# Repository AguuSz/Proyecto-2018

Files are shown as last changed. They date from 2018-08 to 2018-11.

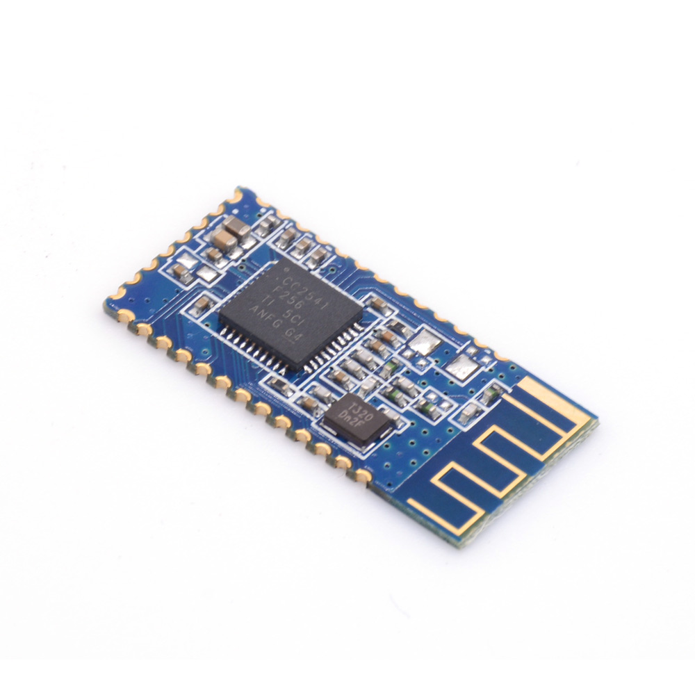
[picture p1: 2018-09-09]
Imagenes/hm_10_03.jpg

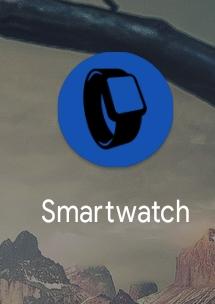
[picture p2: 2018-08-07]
Imagenes/2.jpeg

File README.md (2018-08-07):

# Proyecto 2018

En este repositorio se iran incluyendo los avances realizados en Arduino, ademas de ir adjuntando la bitacora actualizada para el proyecto 2018 "SmartWatch" del CET N°9. Realizado por Agustin Sepulveda, Marcos Marzeniuk y Emanuel Azurra.

Logo del colegio

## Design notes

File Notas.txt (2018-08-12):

// NOTAS //

La pantalla utilizada en el tutorial es de 28 * 64 OLED la cual estaba usando I2C y SSD1306 driver chip. Como estamos usando una diferente, lo mas seguro es que tengamos que usar unas librerias graficas diferentes y modificar el codigo fuente de Arduino

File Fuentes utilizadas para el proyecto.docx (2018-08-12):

Fuentes utilizadas para el proyecto

http://www.instructables.com/id/Make-your-own-smart-watch/

https://catinean.com/2015/03/07/creating-a-watch-face-with-android-wear-api/

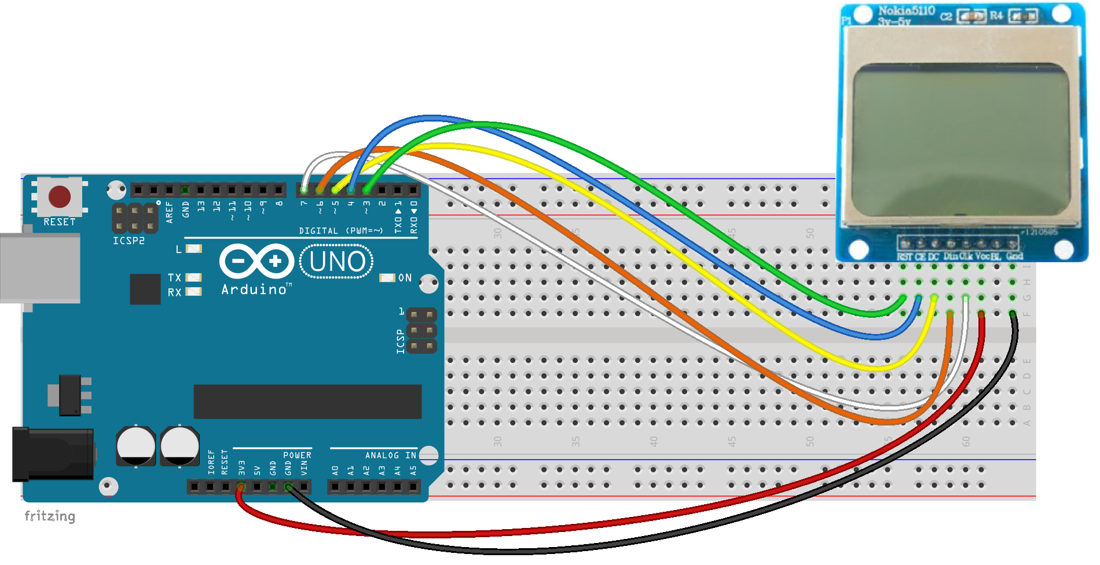
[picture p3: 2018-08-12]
Imagenes/Esquema de conexion.png

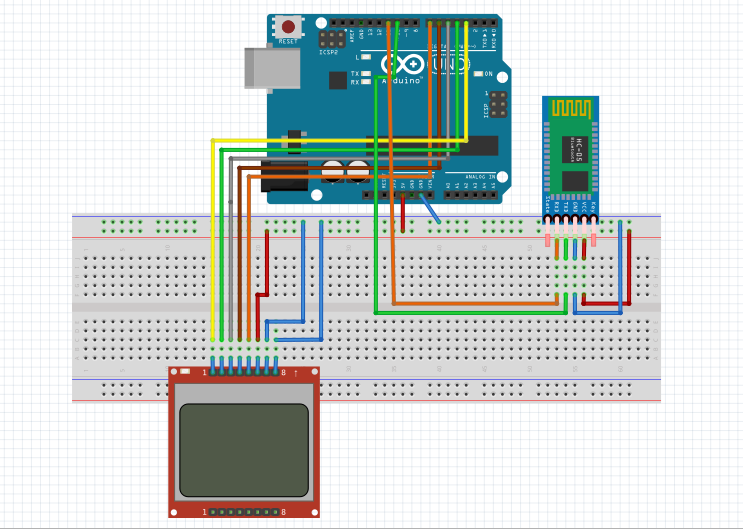
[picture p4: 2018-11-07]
Graficos PS/Esquema CleverClock.png

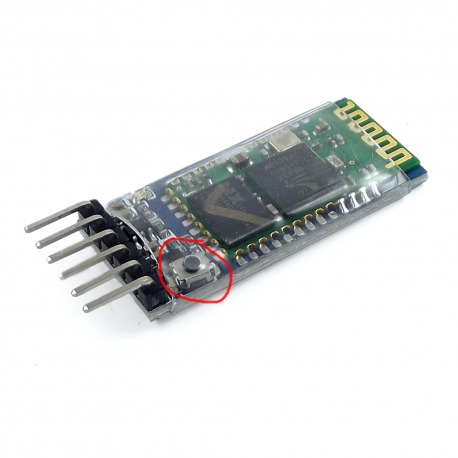
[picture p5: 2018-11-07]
Imagenes/HC 05.png

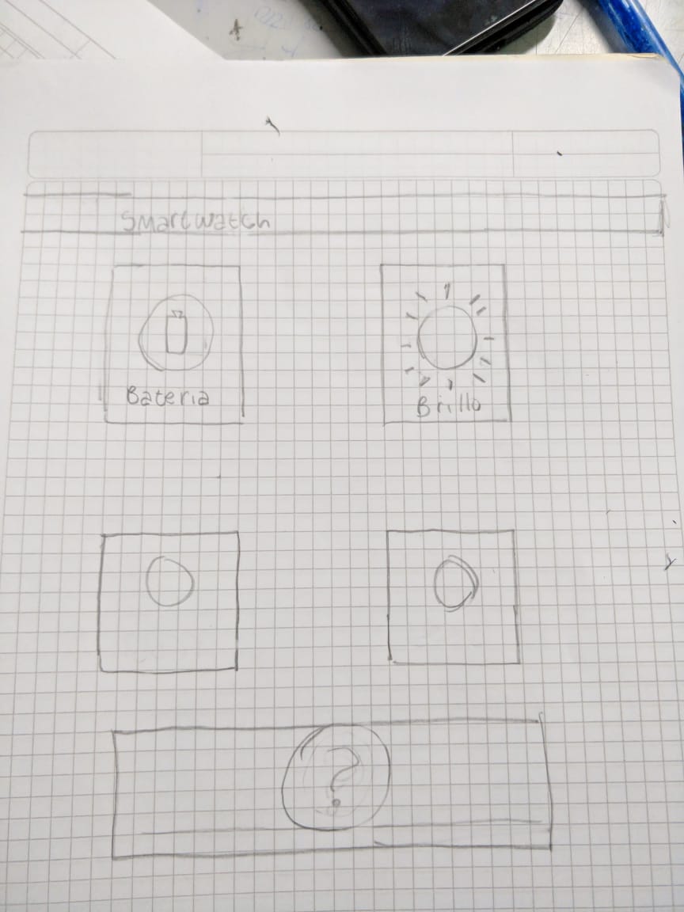
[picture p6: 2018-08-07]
Imagenes/Croquis.jpeg

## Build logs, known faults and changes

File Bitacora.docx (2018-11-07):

Bitacora

CleverClock

Agustín Sepúlveda, Marcos Marzeniuk, Emanuel Azcurra

CET N°9

Proyecto 2018

Grupo integrado por: Sepúlveda Agustín, Marcos Marzeniuk y Azcurra Emanuel.

Luego de discutir varias ideas, entre las cuales se encontraban un karting (descartado por su elevado costo) y una bici a motor (descartada por disgusto en el grupo), llegamos a la conclusión de este año querer hacer algo más electrónico, algo que se pueda hacer fuera de los talleres y que sea fuera de lo que se da en taller. Por eso es que, llegamos a la conclusión de realizar un SmartWatch (reloj inteligente) el cual fuera capaz de funcionar como un reloj común y corriente indicando la hora, pero además notificar a la persona si le llega algún mensaje o alguna notificación en general a su celular. La idea también es incrementar sus funcionalidades, pero esta va a puramente depender de los conceptos que se vayan aprendiendo a lo largo del año.

Conocimientos que se poseen en el grupo: en lo que respecta a electrónico, se sabe toda la parte de conexionado y, además, una base en programación bastante útil para poder darle ordenes al reloj.

Materiales estaríamos utilizando:

- Un micro controlador Arduino (en este caso, lo ideal sería trabajar con el más pequeño de todos, que sería el Pro mini).
- Un módulo bluetooth para poder conectarlo al celular y de esa manera estar comunicados.
- Una pantallita OLED.
- Una batería, preferentemente de LiPo (Polímero de litio).
- Cables.
- Un interruptor o botón.
- Una resistencia de 10k‎Ω.

Todos estos materiales los estaríamos comprando tanto en internet como en tiendas físicas. En internet compraríamos lo que sería el micro controlador Arduino que es lo más complicado de conseguir debido al tamaño y lo demás se podría conseguir en tiendas de Cipolletti.

Maquinas a estar utilizando:

- Soldadora de estaño.
- Computadora.

El espacio de construcción en el que se llevaría a cabo el proyecto sería en la casa, debido a la comodidad que brinda el tener que trabajar todo con código.

Para el proyecto, no estaríamos siendo asesorados por nadie, toda cosa que hagamos va a ser por conocimientos que ya tenemos o que se irán adquiriendo a lo largo del año por internet, a través de tutoriales y videos.

Día 10/06

Nos juntamos a investigar sobre los componentes a utilizar, hasta el momento no tenemos muy claro cuales usar, por ejemplo, en el tema de la pantalla, no sabemos si utilizar una OLED o una LCD. De todas formas, hasta ahora tenemos 3 en mente:

- Display Oled 1.3 128x64 I2c Ssh1106
- Display Lcd Ard Pic Arm Nokia 5110 Spi 84x48

También estuvimos viendo el tema de incluir una Pantalla táctil para que al usurario se le haga más cómodo su uso. Estuvimos viendo una pantalla, pero, de todas formas, en la tienda que encontramos la pantalla táctil que venden es demasiado grande para lo que queremos hacer. Aquí la pantalla:

- Pantalla Tactil Tft Lcd Color 2.4 Y Lector Micro Sd Ard Mona

Luego estuvimos módulos bluetooth. Los mejores que encontramos en stock en varias tiendas en línea fueron:

- Modulo Bluetooth 2.0 Bl3256
- Modulo Bluetooth BLE112-A-V1
- Los módulos de bluetooth HC-05 y HC-06

Día 14/06

Luego de haber hablado con Pablo Sánchez y que nos haya guiado en que tiendas comprar y como seleccionar los componentes, nos ayudó al ver que componentes nos convenía usar. Además de todo esto, nos dio un punto de partida para empezar a trabajar.

Nos dimos cuenta que el mayor problema al que vamos a enfrentar es seleccionar los componentes adecuados y que además ocupen el volumen adecuado para que no sea demasiado grande para la muñeca.

En este caso, las Arduinos más chicos nos podrían servir, pero en caso de que necesitemos aún más reducir el tamaño, Pablo dijo que nos podría quitar partes innecesarias de una placa.

De todas formas, estamos viendo las posibilidades de poder encargar una placa (PCB) a diseño, pero de ser así tendríamos que hacer el diseño de la plaqueta. Las ventajas que nos ofrece esta opción son numerosas porque nos quedaría del tamaño que nosotros requerimos, ya que solo estarían presentes las conexiones que necesitamos.

Estuvimos dibujando varios diseños que va a tener la pantalla principal pero todavía no estamos seguros debido a que no sabemos las funciones totales que va a tener el reloj, se irán incluyendo diseños a lo largo del proyecto.

Día 18/06

Hoy encargamos en internet los primeros componentes, y los esenciales, para poder crear un prototipo funcional y aprender a programar en Arduino (microcontrolador Arduino Uno R3 y una pantalla de Nokia 5110). La tienda que usamos es: www.monarcaelectronica.com.ar. Esperamos su llegada el viernes 22/06 o el 25/06.

Día 27/06

Recién hoy llega la plaqueta Arduino Uno R3 y la pantalla del Nokia 5110. Con estos componentes vamos a estar practicando código para manejar bien el tema de la pantalla. Por otra parte, Agus está aprendiendo el lenguaje de programación Java para que cuando sea necesario la aplicación para el sistema operativo de celular Android no haya ningún inconveniente. Ema está encargándose de ver el tema de los materiales que vamos a usar y Marcos como encajar todos los componentes para lograr reducir al máximo el tamaño y que sea un reloj compacto, sin perder ninguna funcionalidad.

Día 05/07

Hoy, ya con un poco de experiencia ganada en Arduino y de electrónica, decidimos conectar la pantalla y el Arduino a una Protoboard y probar código, esperando que podamos imprimir algo en la pantalla y poder controlarla. Los resultados obtenidos no fueron los esperados ya que al seguir el conexionado que nos proveía una librería de la pantalla, lo único que hacía era prender la luz de fondo de la pantalla, pero no nos dejaba transmitirle texto. Vamos a tratar de solucionar este error el día miércoles 11/07 con Pablo Sánchez ya que él tiene mucho más conocimiento en este campo que nosotros. Aquí una foto de cómo se veía la pantalla con el conexionado ya hecho y solo con la luz de fondo:

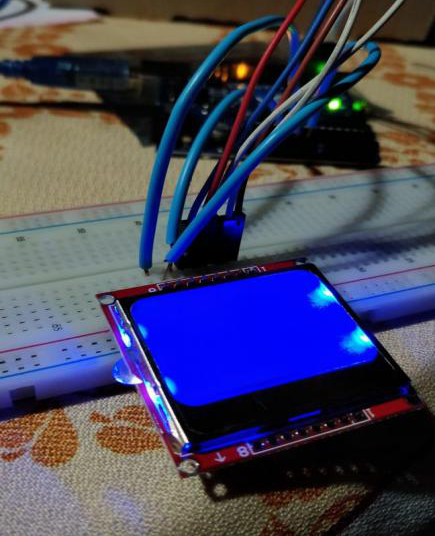
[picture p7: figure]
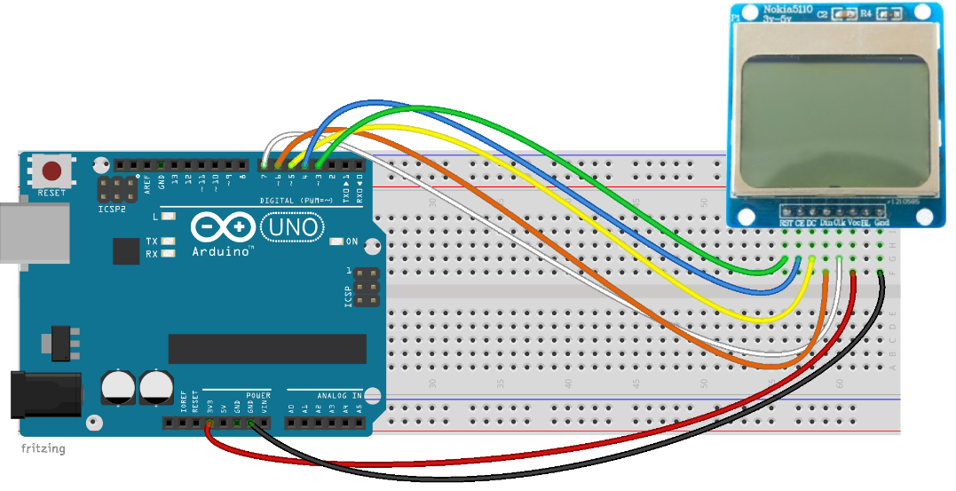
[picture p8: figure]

Día 06/07

Viendo que la pantalla no anda y no tenemos idea del porqué, vamos a esperar hasta el miércoles para hablar con Pablo Sánchez, podríamos ir el lunes, pero por desgracia, es feriado. Mientras tanto, vamos a ir diseñando la parte gráfica de la aplicación de Android que queremos realizar para emparejar el celular junto con el reloj.

Día 07/07

Hoy día nos planteamos como queríamos hacer el tema de la aplicación para Android. Básicamente, lo único que hicimos fue realizar un croquis con su diseño. Aquí el croquis:


Día 08/07

Hoy, conseguimos pasar del diseño de un croquis a una aplicación real, llevó bastante trabajo, pero logramos realizar, aunque sea la mayor parte de la parte gráfica de la aplicación (como se va a ver). Cabe recalcar que hay cosas que pretendemos cambiar, como lo son algunos nombres y los iconos. Aquí unas imágenes:

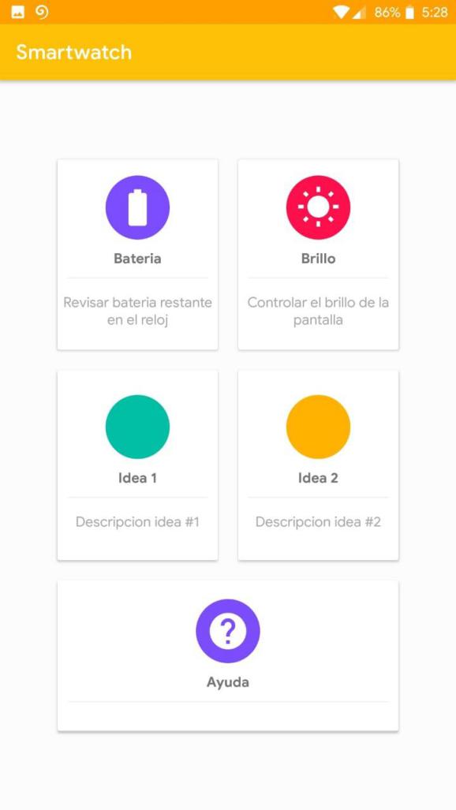
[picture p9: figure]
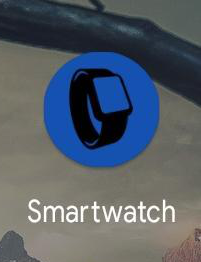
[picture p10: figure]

Pantalla principal.

Icono de la app.

Como aparece en los ajustes.

De todas maneras, se pretenden añadir algunas cosas más, tales como un menú que se deslice por la izquierda, la opción de cambiar la apariencia de la aplicación y, de ser posible, lo ideal sería poder poner transiciones personalizadas a los botones.

Día 11/07

En el día de hoy, Pablo nos ayudó a resolver el problema que teníamos con la pantalla, el cual era que prendía, pero no imprimía nada en la misma. Todo esto resultó en que los pines, al no estar soldados, no hacían un contacto eficiente, por lo que al mínimo movimiento ya perdía información, resultando en no imprimir nada. Soldamos los cables dejándolos bien fijos y ahora anda todo de 10. Con respecto a la aplicación de Android pensamos algunas ideas las cuales falta implementarla, aunque sea solamente en la parte gráfica por ahora. Adjuntamos una screenshot de Android Studio para que se vea aunque sea un poco de la estructura que va llevando la aplicación.

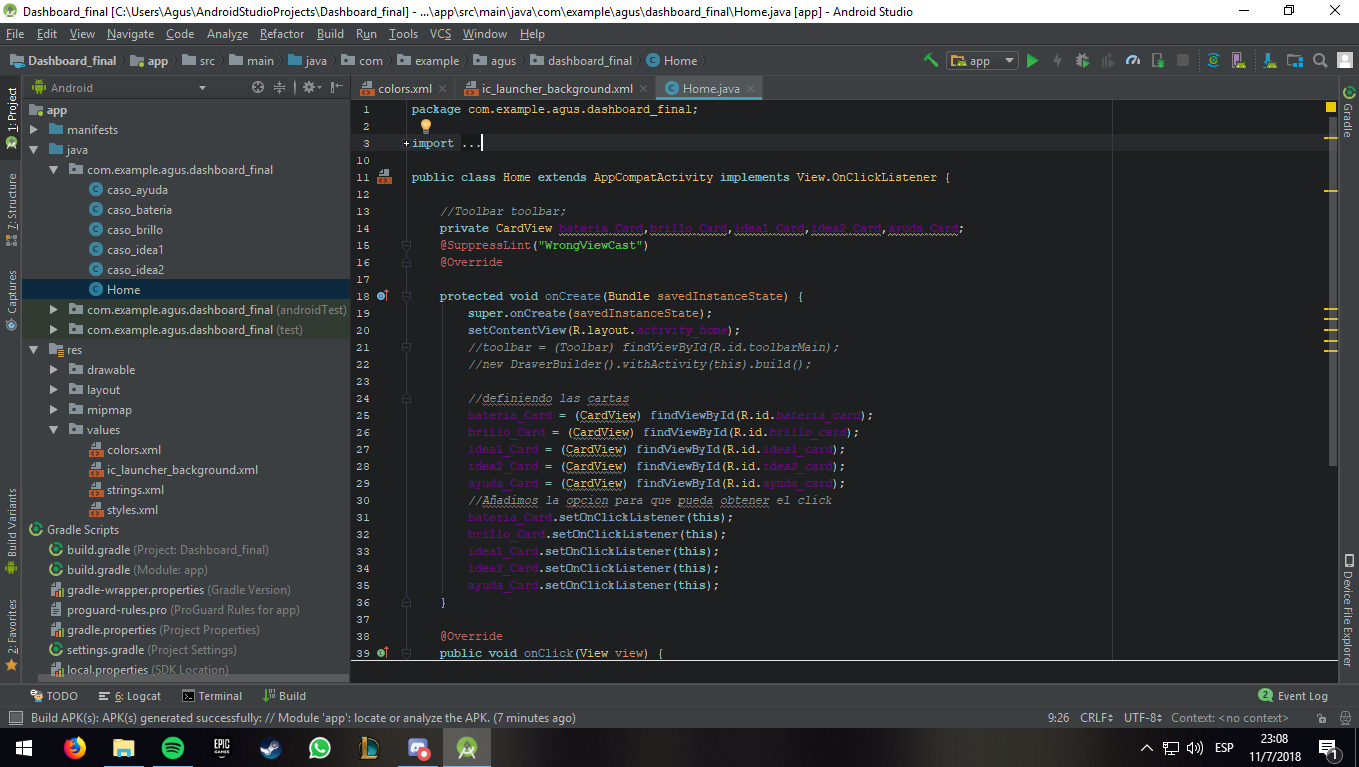
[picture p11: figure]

Día 08/08

Hoy día aprendimos a poder imprimir texto en la pantalla. Incluyendo las librerías de Adafruit, que es la necesaria para hacer andar la pantalla de una manera simple y eficaz.

El comando necesario para imprimir texto es el siguiente:

Primero definimos el tamaño de la letra:

display.setTextSize(1);

Luego definimos el color de la letra, en nuestro caso, como estamos utilizando una pantalla monocromática, el color va a ser siempre el mismo (negro):

display.setTextColor(BLACK);

Luego procedemos a imprimir texto:

display.println(“TEXTO A IMPRIMIR”);
display.display();

Luego intentamos imprimir el logo del colegio, pero resulto en un intento fallido debido a la falta de tiempo y que el logo esta coloreado. El hecho de que nuestra pantalla sea monocromática imposibilita el tema de los colores, y en caso de querer imprimir de todas formas, hay que pasarla a un color blanco y negro. Pero de nuevo, por la falta de tiempo no pudimos.

Día 14/08

Hoy día nos pusimos en campaña para idear el sistema de conteo que va a tener Arduino para simular un reloj, ya que cuando tengamos un módulo Bluetooth, vamos a tener que sincronizar la hora cada tanto y para que no sea constante esa transferencia la cosa es que se pueda sostener por sí solo.

Nuestro intento fue exitoso hasta cierta parte, ya que crear ese sistema es fácil, pero el problema es mostrarlo en la pantalla con la posición que nosotros queramos, sin la necesidad de limpiar la pantalla completamente cada vez que se actualicen los minutos.

Una vez listo el sistema de conteo, pasaremos al realizado de el grafico de un reloj, en caso de que se quiera un reloj parecido a los analógicos (con agujas).

Día 15/08

Luego de una charla con Pablo Sánchez, nuestro mentor en el proyecto, decidimos comprar el modulo Bluetooth HM-10 y un pack de cables a través de Monarca Electrónica. Mientras que llega el pedido, seguimos diseñando y probando métodos de conteo para que pueda almacenar la hora de manera correcta sin retrasos ni nada. La gran dificultad que se presenta es el tema de que las librerías que hay disponibles para trabajar con la pantalla son bastante pobres cuando hablamos de documentación. Sin una librería que nos permita el hacer lo que queramos con la pantalla se complica el hecho de acomodar las cosas.

También cabe aclarar que nuestro proyecto entero lo subimos a una plataforma llamada “GitHub”, la cual hace más fácil el trabajo en equipo y también se mantiene actualizada ya que cualquier cambio que hacemos automáticamente se sube. El link es el siguiente:

- https://github.com/AguuSz/Proyecto-2018

Día 16/08

Hoy Marcos y Emanuel pasaron la tarde con el profesor de laboratorio, el cual les estuvo enseñando las bases de Arduino y también guiando un poco para poder idear el algoritmo del reloj. El trabajo que realizaron hoy fue una especie de semáforo, la cual al iniciar prendía un led, al cabo de unos segundos lo apagaba y prendía otro. Video adjunto en la carpeta “Videos” que se puede encontrar en GitHub.

Día 17/08

Emanuel y Marcos siguen atendiendo al curso que dicta el profesor de laboratorio. Ya encargamos el modulo Bluetooth y estamos a la espera de que llegue, se espera que llegue aproximadamente el día 24/08, a más tardar el 29/08. Mientras tanto, seguimos con el sistema de conteo, pero la pantalla no parece ser muy flexible para ser trabajada. Se plantea un posible cambio de pantalla, aunque su costo es medianamente elevado, se sigue planteando la posibilidad.

Día 24/08

Llego el modulo Bluetooth, vamos a estar esperando el día para ir a hablar con Pablo acerca de cómo podemos soldarle los pines para poder utilizarlo. Adjuntamos imagen del módulo:

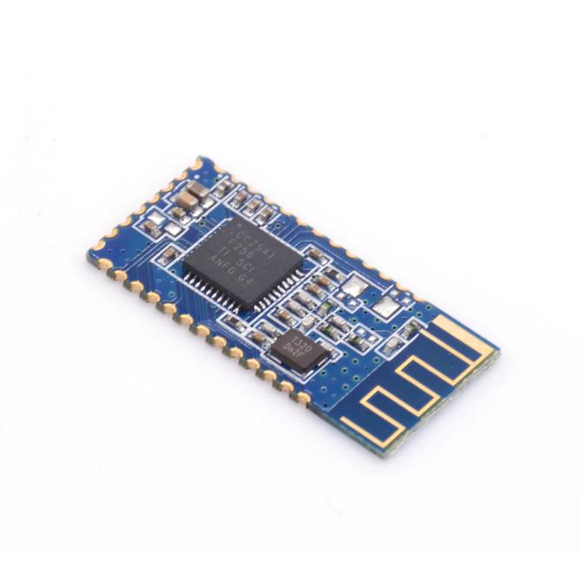
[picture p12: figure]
hm_10_03

Día 29/08

Con la ayuda de código de internet, logramos crear el sistema de conteo y que lo muestre de la manera que nosotros queremos. De todas formas, hay que limpiar el código ya que hay que adaptarlo a nuestro proyecto.

Respecto al módulo Bluetooth, Pablo nos dijo que teníamos 2 alternativas: soldarle unos pines, lo cual iba a ser complicado, y 2, soldar el modulo en si a una placa aparte y utilizar la placa para conectarlo a la protoboard.

Tendremos que esperar hasta el día lunes 03/09 para poder hablar con Pablo por el tema de la limpieza de código, no lo podemos hacer nosotros porque hay muchas cosas del código las cuales no comprendemos.

Día 18/09

La idea de comprar un Nuevo módulo bluetooth fue descartada porque su costo era muy elevado. Por lo que decidimos diseñar una plaqueta desde 0 y así, dar uso al módulo.

Nos llevó bastante tiempo el diseño de la plaqueta, pero lo logramos. Imprimimos dicho diseño en papel fotográfico para luego plancharlo directamente a una plaqueta.

El diseño es el siguiente:

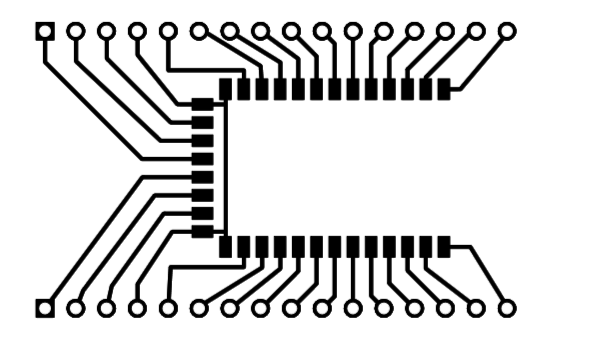
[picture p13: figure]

Ema va a ser el encargado de llevar a cabo el planchado del diseño que creamos a una placa de cobre, donde luego se procederá soldando los extremos para que haya continuidad.

Día 1/10

La plaqueta sigue siendo creada, mientras tanto, aprovechamos el tiempo y estamos viendo maneras de perfeccionar el código del reloj que habíamos creado para que ahora pueda haber algunas cosas parecidas a gráficos y, además, que los textos presentes puedan ser mostrados con diferentes fuentes. El objetivo de todo esto, es para que quede mejor a la vista, ya que contara con un diseño más atractivo.

Luego de una examinada intensa a los videos de YouTube que hay, pudimos rescatar bastante información al respecto, más que nada de youtubers de habla inglesa porque en español no hay mucha información que sirva de algo.

Los videos que más nos sirvieron fueron los siguientes:

https://www.youtube.com/watch?v=cwsCxUhHbQM

https://www.youtube.com/watch?v=t31n6Y-0bYg (este sobre todo nos ayudó bastante)

Día 2/10

Conseguimos seguir bastante bien los pasos de los videos mencionados anteriormente y logramos lo siguiente:

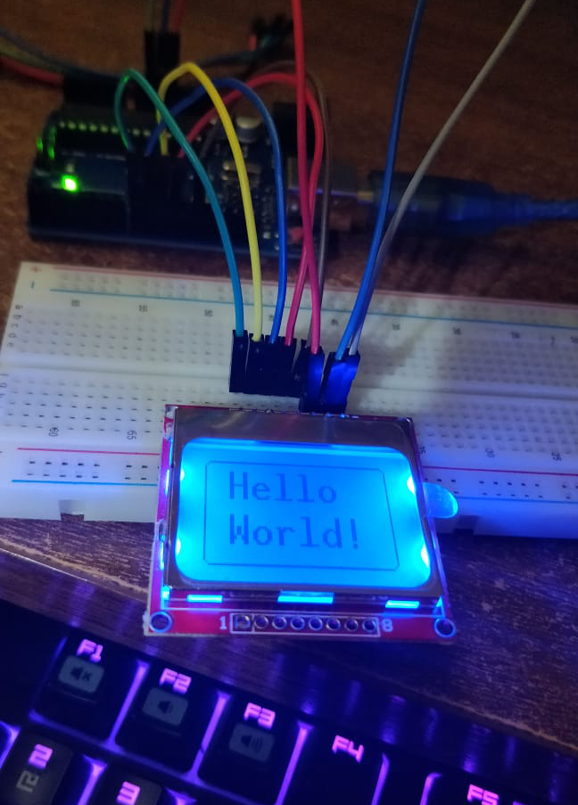
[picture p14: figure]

Si bien es algo básico y simple, la librería U8GLIB nos quedó bastante claro el hecho de cómo usarla, y es muchísimo más cómoda que la que anteriormente estábamos usando (Adafruit 8544).

Los próximos avances seguro serán acerca de ya un diseño de reloj.

Día 3/10/18

Conseguimos completar el tema del módulo bluetooth. Lo soldamos a la plaqueta que diseñamos y cortamos, y ahora está listo para su uso. Una vez hayamos acomodado bien el tema de las fuentes y diseño que va a tener nuestro reloj, vamos a meternos en el asunto de cómo hacer que el Arduino interprete las señales que le mandemos desde nuestro celular y así poder mostrar el texto en la pantalla.

Adjuntamos imágenes de como quedo el modulo bluetooth ahora soldado:

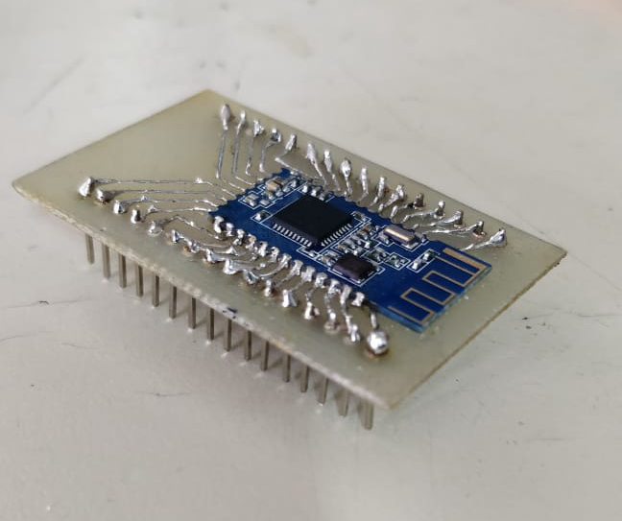
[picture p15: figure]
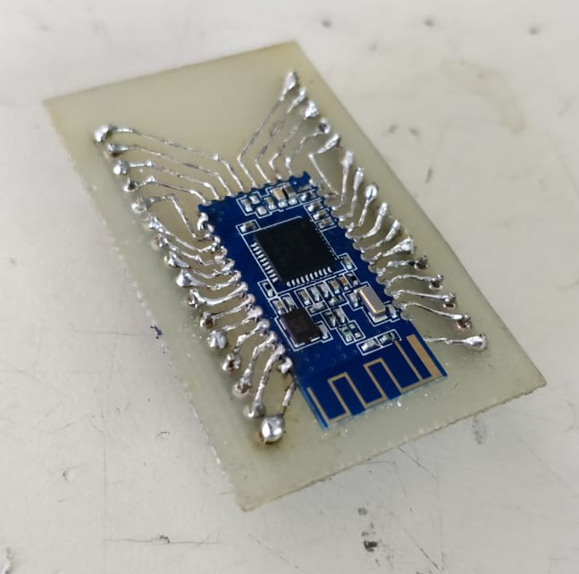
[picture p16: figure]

Eso sí, hubo un intento de la plaqueta la cual no salió bien, pero por el momento no tenemos fotos, cuando tengamos las adjuntaremos en la bitácora.

Con respecto a la aplicación de Android, por el momento la estamos dejando media abandonada mientras nos concentramos en llevar a cabo el tema de la interpretación de Arduino. De otro modo, nos perderíamos bastante ya que son tecnologías totalmente diferentes entonces es muy fácil perderse y frustrarse por no poder realizar las cosas.

Día 7/10/18

Hoy nos pusimos a trabajar con el tema del módulo Bluetooth, pero nos surgió un problema. Resulta que el modulo bluetooth trabaja con un voltaje de 3,3v, mientras que la pantalla, actualmente está corriendo con 5v. Por lo tanto, posibles soluciones son: usar un divisor de tensión que podemos hacer con unas 2 resistencias (este método requeriría el cálculo de las resistencias a usar para que hayan 3,3v de salida) o bien comprar un regulador de voltaje (esta es la opción más fácil).

Cambiando de tema, estamos viendo una librería llamada “time” con la cual podemos hacer la función de un reloj sin la necesidad de utilizar un módulo RTC (lo que hace este módulo es mantener constancia de la hora cosa que nunca se pierda). No queremos usar un módulo RTC porque creemos que, al menos para el prototipo, no hace falta, ya que se puede sincronizar con el celular por medio de bluetooth y listo.

También estamos viendo la posibilidad de agregarle un botón cosa que al apretar ese pulsador se sincronice la hora.

Otra cosa que se está viendo un poco más de fondo es el tema de las diferentes “paginas” por la cual va a estar compuesto el reloj. La idea sería que la primera página muestre lo que sería la hora, fecha y batería. Una segunda página va a ser necesaria para cuando el reloj este recién prendido y haya que sincronizarlo, así de esa manera, no arroja una hora hasta estar sincronizado.

Día 10/10/18

El tema de “paginas” ya está resuelto, creamos una función para que la creación de las mismas sea más fácil.

Logramos arreglar un problema que había con la sincronización, que al pasar 5 minutos se desincronizaba y hacia que la pantalla vuelva al inicio de “Sin sincronizar”.

Analizamos la idea de implementar un registro de la hora en la memoria EEPROM de Arduino, pero no tenemos bien claro COMO implementarlo de manera eficiente.

Surge un problema con el modulo bluetooth que no podemos hacer que entren pines que acompañen, por lo que lo cortamos un poco a los lados para que logre entrar en la protoboard correctamente.

Pero luego de la charla con pablo lo limamos para que entre correctamente los pines.

Analizamos posibilidades de divisores de voltaje…

Día 17/10

Nos surge el problema de que el modulo bluetooth no está respondiendo a la conexión, ni siquiera a la que se le brinda por medio de la PC. Luego de buscar durante varias horas información acerca del módulo, decidimos ir a hablar con Pablo a ver si nos podía ayudar a hacerlo funcionar correctamente.

De todas las cosas que intentamos para hacerlo andar ninguna funciono, por lo que Pablo nos comentó que él está comprando unas cosas con otra escuela, por lo que podemos aprovechar y encargarle un módulo bluetooth. El que le vamos a encargar es el HC-06, uno el cual pablo está acostumbrado a trabajar, entonces la ayuda que vamos a recibir va a ser mucha mayor.

Seguimos viendo el tema de la aplicación de Android..

Día 22/10

Seguimos sin respuesta de Pablo. Por lo que decidimos invertir el tiempo que tenemos mientras llega el módulo en investigar algo acerca de la comunicación entre Celular-Modulo.

Una vez tengamos el módulo, creeríamos que ya terminaríamos el proyecto, ya que es lo único que nos falta. Además el módulo este que nos tiene que llegar ya tiene los pines en la parte inferior de serie, por lo que es llegar, conectar y usar, muchísimo más simple si lo comparamos con el módulo el cual estábamos trabajando.

Día 23/10

La comunicación parece ser mucho más simple de lo que pensamos, incluso hay aplicaciones ya hechas con las que se puede testear y usar tranquilamente el tema de las notificaciones en pantalla, por lo que nuestra teoría de que cuando llegue el módulo nos quedaría relativamente poco, va tomando cada vez más sentido.

Se tiene pensado presentar un prototipo proyectado en la Protoboard y recién el año que viene construirle un cuerpo y optimizar código, además de también reducir el tamaño lo más posible para que quede lo más cómodo a la muñeca.

Día 26/10

Este día nos llegó el modulo bluetooth, y con el empezamos a ver las comunicaciones seriales que se tienen que hacer entre el Arduino, el celular y el modulo bluetooth.

Día 27/10

Hoy, ya con el modulo bluetooth (HC-05) realizamos todo el cableado que va a llevar el producto final. Adjuntamos imágenes del conexionado:


Día 28/10

Logramos crear las diferentes pantallas de bienvenida y carga para que quede mejor visualmente. Seguimos analizando tema de comunicación entre celular, bluetooth y Arduino.

Implementado medidor de batería, aunque actualmente al estar alimentado a la PC, siempre va a estar marcando 100%.

Día 1/11

Estos días hemos avanzado bastantemente, pero nos olvidamos de incluir todas las tareas que habíamos realizado. Básicamente lo que hicimos fue conseguir una aplicación, llamada “Notiduino” la cual hace que cuando llegue una notificación de alguna aplicación que hayamos elegido, esta mande un valor por medio del módulo bluetooth. Un ejemplo de esto, seria: nosotros elegimos WhatsApp como una aplicación, y cuando llegue un mensaje de esta aplicación, va a mandar una “w” al Arduino a través del módulo bluetooth.

De esta manera logramos crear un algoritmo que registre el dato este que se está mandando, y en base a que dato sea, realice una acción u otra. En caso de que fuera WhatsApp, muestre en pantalla que ha llegado un nuevo mensaje por WhatsApp, y en cambio si fuera Instagram, mostraría que el mensaje que llego es de Instagram. Para un primer prototipo, decidimos incluir estas 2 aplicaciones, pero a la larga iremos incluyendo más.

Después, otra cosa que también cambio, fue el tema de la hora. Al final no lo vamos a estar sincronizando cada 3 horas, ni sincronizarlo del todo. Lo que vamos a hacer es comprar un módulo RTC (Real Time Clock) que lo que haga es llevar registro del transcurso de la hora en todo momento, incluso cuando el Arduino se encuentra apagado (esto lo hace porque tiene incorporado una batería de 5v que hace que se mantenga en funcionamiento. Dicha batería tiene una duración de aproximadamente 2 años). Estamos esperando que Pablo nos dé una respuesta de donde conseguir una y el precio así la podemos incorporar. El tiempo de incorporado, va a ser mínimo, ya que es bastante simple el ajustar la hora inicial y dejarla ahí. Y con respecto a su tamaño, no va a haber ningún drama porque, de hecho, es bastante diminuto.

Día 3/11

Ya con el módulo RTC, lo ajustamos a la fecha actual y ya está listo para ser utilizado en conjunto con los otros componentes. Técnicamente el proyecto ya está terminado, solo queda mejorarlo / pulirlo o agregarle nuevas funciones, pero debido a la falta de tiempo creemos que lo cerraremos aca.

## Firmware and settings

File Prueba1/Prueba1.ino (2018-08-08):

/*********************************************************************
This is an example sketch for our Monochrome Nokia 5110 LCD Displays

  Pick one up today in the adafruit shop!
  ------> http://www.adafruit.com/products/338

These displays use SPI to communicate, 4 or 5 pins are required to
interface

Adafruit invests time and resources providing this open source code,
please support Adafruit and open-source hardware by purchasing
products from Adafruit!

Written by Limor Fried/Ladyada  for Adafruit Industries.
BSD license, check license.txt for more information
All text above, and the splash screen must be included in any redistribution
*********************************************************************/

#include <SPI.h>
#include <Adafruit_GFX.h>
#include <Adafruit_PCD8544.h>

// Software SPI (slower updates, more flexible pin options):
// pin 7 - Serial clock out (SCLK)
// pin 6 - Serial data out (DIN)
// pin 5 - Data/Command select (D/C)
// pin 4 - LCD chip select (CS)
// pin 3 - LCD reset (RST)
Adafruit_PCD8544 display = Adafruit_PCD8544(7, 6, 5, 4, 3);

// Hardware SPI (faster, but must use certain hardware pins):
// SCK is LCD serial clock (SCLK) - this is pin 13 on Arduino Uno
// MOSI is LCD DIN - this is pin 11 on an Arduino Uno
// pin 5 - Data/Command select (D/C)
// pin 4 - LCD chip select (CS)
// pin 3 - LCD reset (RST)
// Adafruit_PCD8544 display = Adafruit_PCD8544(5, 4, 3);
// Note with hardware SPI MISO and SS pins aren't used but will still be read
// and written to during SPI transfer.  Be careful sharing these pins!

#define NUMFLAKES 10
#define XPOS 0
#define YPOS 1
#define DELTAY 2


#define LOGO16_GLCD_HEIGHT 16
#define LOGO16_GLCD_WIDTH  16

void setup()   {
  Serial.begin(9600);

  display.begin();
  // init done

  // you can change the contrast around to adapt the display
  // for the best viewing!
  display.setContrast(50);

  display.display(); // show splashscreen
  delay(2000);
  display.clearDisplay();   // clears the screen and buffer

  // draw a single pixel
  display.drawPixel(10, 10, BLACK);
  display.display();
  delay(2000);
  display.clearDisplay();

  // draw multiple rectangles
  testfillrect();
  display.display();
  delay(2000);
  display.clearDisplay();

  // draw the first ~12 characters in the font
  testdrawchar();
  display.display();
  delay(2000);
  display.clearDisplay();

  // text display tests
  display.setTextSize(1);
  display.setTextColor(BLACK);
  display.setCursor(0,0);
  display.println("Hello, world!");
  display.setTextColor(WHITE, BLACK); // 'inverted' text
  display.println(3.141592);
  display.setTextSize(2);
  display.setTextColor(BLACK);
  display.print("0x"); display.println(0xDEADBEEF, HEX);
  display.display();
  delay(2000);

void loop() {
  
}



void testdrawchar(void) {
  display.setTextSize(1);
  display.setTextColor(BLACK);
  display.setCursor(0,0);

  for (uint8_t i=0; i < 168; i++) {
    if (i == '\n') continue;
    display.write(i);
    //if ((i > 0) && (i % 14 == 0))
      //display.println();
  }    
  display.display();
}

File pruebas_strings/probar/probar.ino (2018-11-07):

// Buffer to store incoming commands from serial port
#include <SoftwareSerial.h>
String inData;

SoftwareSerial miBT (10,11);

void setup() {
    Serial.begin(9600);
    miBT.begin(38400);
    Serial.println("Serial conection started, waiting for instructions...");
}

void loop() {
    while (miBT.available() > 0)
    {
        char recieved = miBT.read();
        inData += recieved; 

        // Process message when new line character is recieved
        if (recieved == '\n')
        {
            Serial.print("Arduino Received: ");
            Serial.println(inData);

            // You can put some if and else here to process the message juste like that:

            if(inData == "h\n"){ // DON'T forget to add "\n" at the end of the string.
              Serial.println("OK. Press h for help.");
            }

            if(inData == "t\n"){ // DON'T forget to add "\n" at the end of the string.
              
            }
          
            if(inData >= 1357041600) {
              Serial.println("Tiempo establecido correctamente");
            }


            inData = ""; // Clear recieved buffer
        }
    }
}

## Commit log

2018-08-08 Agregado de test arduino
2018-08-08 Impresion de texto
2018-08-08 Intento de imprimir logo
2018-08-09 Intento de imprimir un logo
2018-08-15 Creacion sistema de reloj
2018-08-23 Incluida carpeta de videos
2018-09-09 Primera version de graficos PS
2018-10-07 Subida de archivos arduino
2018-10-07 Arduino actualizado
2018-11-04 Importacion de esquemas
    [Esquema cleverclock.fzz]
